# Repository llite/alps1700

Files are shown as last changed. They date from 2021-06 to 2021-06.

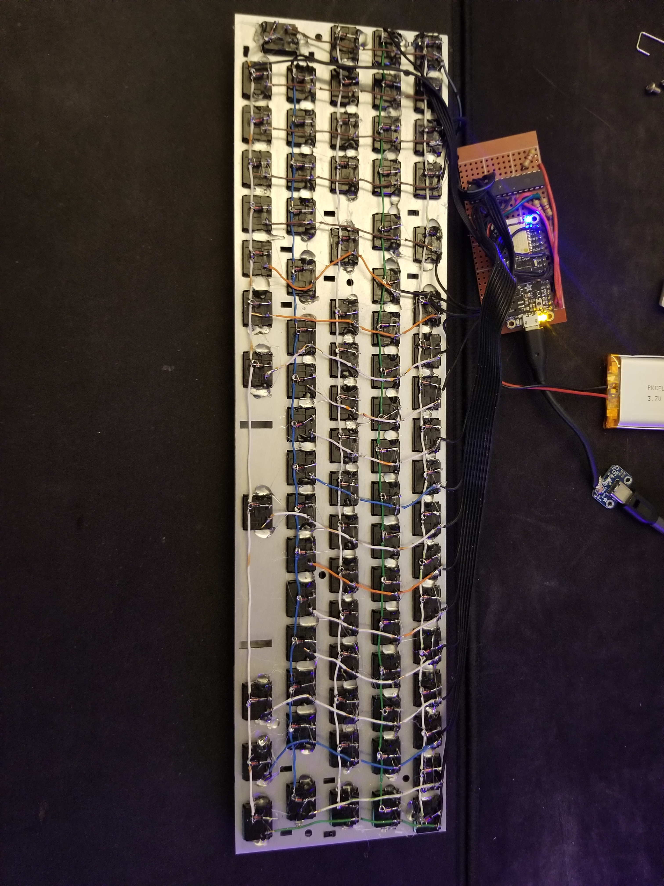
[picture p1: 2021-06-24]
images/20210624_172025.jpg

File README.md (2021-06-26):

# alps1700

A custom handwired keyboard with a similar layout to 1800 sans the function row and more compact.

Specs:
- Bluetooth LE
- USB C
- Alps SKCM Cream Damped switches
- 2000mAh battery
- [Adafruit Feather 32u4 Bluefruit LE](https://www.adafruit.com/product/2829) 

Case is 3d printed out of Formfutura's [Galaxy titanium](https://www.partsbuilt.com/galaxy-pla-titanium-silver-formfutura/). Because of printer bed size limitations it had to be printed in two parts. 

Keycaps and switches are from an [Apple Extended Keyboard II](https://deskthority.net/wiki/Apple_Extended_Keyboard_II), with 3d-printed caps for space, right-shift and num-pad 0.

Firmware is based on [Mike Roberts'](https://github.com/ecopoesis) [NEK type A](https://github.com/qmk/qmk_firmware/tree/master/keyboards/nek_type_a), with a few adjustment to account for the different layout. _Note the diodes MUST be wired in row to column layout for the firmware to work._

I see no reason this couldn't be adapted for cherry mount switches. In theory the only different would be the mounting plate.

## Parts list

| Item | Amount | link |
| --- | --- | --- |
| Alps SKCL/SKCM switches | 81 | [deskthority wiki](https://deskthority.net/wiki/Alps_SKCL/SKCM_series) |
| Keycaps | XX | Up to you |
| Switch mounting plate | 1 | [sendcutsend](https://sendcutsend.com/) |
| Feather 32u4 Bluefruit | 1 | [adafruit](https://www.adafruit.com/product/2829) |
| MCP23017 I/O Expander | 1 | [adafruit](https://www.adafruit.com/product/732) |
| Through-Hole Resistors - 4.7K | 3 | [adafruit](https://www.adafruit.com/product/2783) |
| 1N4148 Diode | 81 | [adafruit](https://www.adafruit.com/product/1641) |
| Perfboard | 1 | [adafruit](https://www.adafruit.com/product/2670) |
| Ribbon cable | 1 | [adafruit](https://www.adafruit.com/product/3890) |
| Solid core cable | 1 | [adafruit](https://www.adafruit.com/product/290) |
| Li-Po battery | 1 | [adafruit](https://www.adafruit.com/product/2011) |
| USB-C breakout | 1 | [adafruit](https://www.adafruit.com/product/4090) |
| m3 Heat-Set Inserts | 6 | [adafruit](https://www.adafruit.com/product/4256) |
| m3x5 bolts | 6 | [boltdepot](https://www.boltdepot.com/Product-Details.aspx?product=18787) |
| Filament | ~300g | [one I used](https://www.partsbuilt.com/galaxy-pla-titanium-silver-formfutura/) |

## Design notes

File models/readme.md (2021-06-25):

All the models needed to make the keyboard.

The case is to large to print in one piece on most 3d-printers so there are split models included. 

Depending on the keycap set you may need to print some keys. There are files for a 6u spacebar, 1.75u right shift, and 1u numpad 0. These are modeled off the AEK2's keycaps which have a different profile than most caps. There are libaries for printing caps like [rsheldiii's KeyV2](https://github.com/rsheldiii/keyV2) in case you need them.

Print list

| Item | Amount |
| --- | --- |
| Case-left | 1 |
| Case-right | 1 |
| Alligment-pin | 2 |
| 6u spacebar | 1 |
| 1.75u r-shift | 1 |
| 1u numpad-0  | 1 |

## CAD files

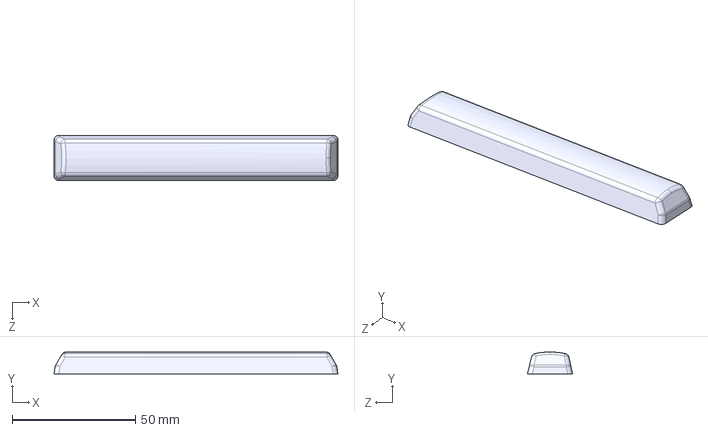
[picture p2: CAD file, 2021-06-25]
models/keycaps/space-6u.STEP
115.0 x 8.90 x 18.3 mm

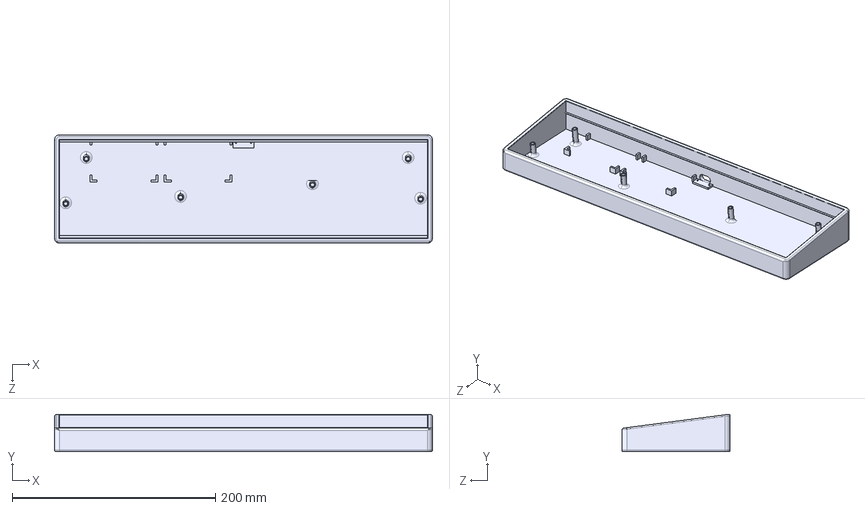
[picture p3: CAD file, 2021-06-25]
models/case.STEP
372.0 x 36.8 x 106.8 mm

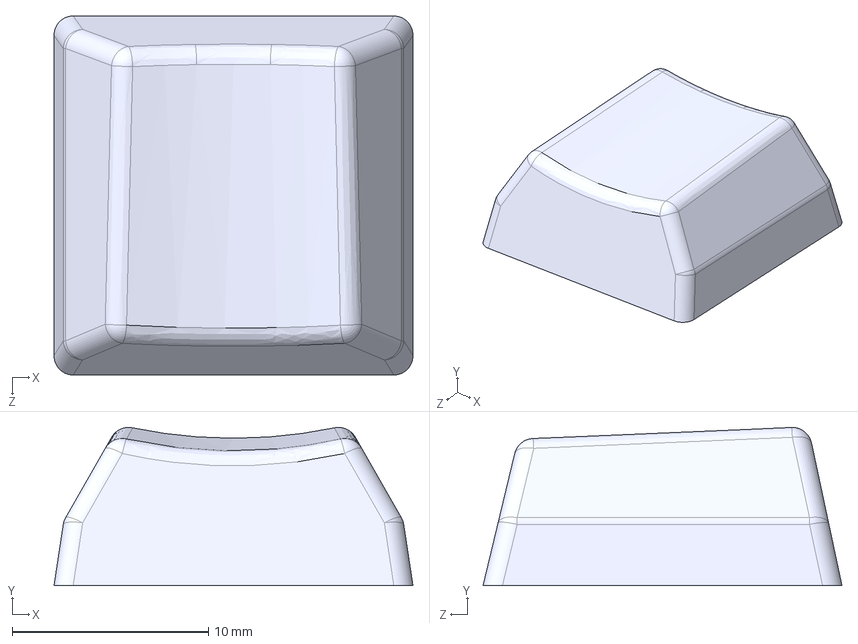
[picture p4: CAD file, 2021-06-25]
models/keycaps/RA-1U.STEP
18.3 x 8.06 x 18.3 mm

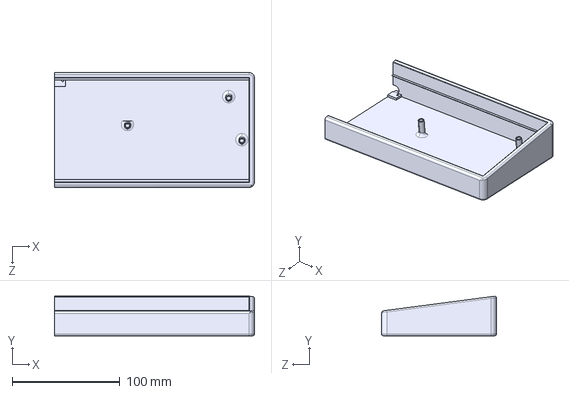
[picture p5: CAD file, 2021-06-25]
models/case-right-half.STEP
186.0 x 36.8 x 106.8 mm

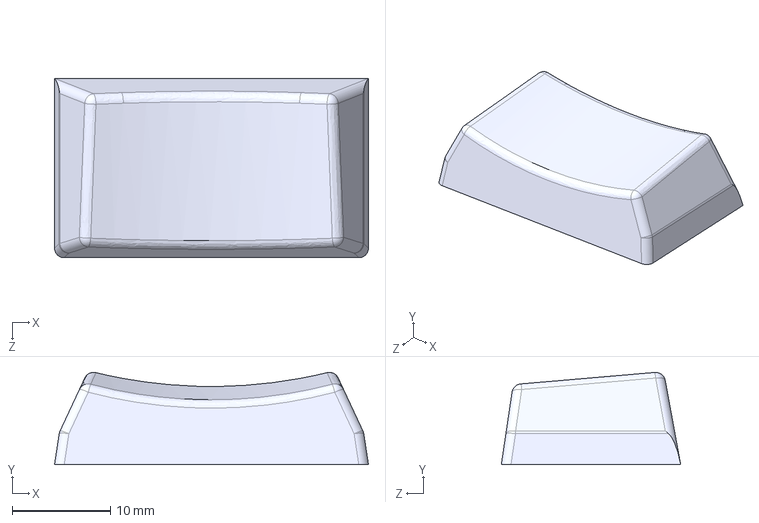
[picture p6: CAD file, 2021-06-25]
models/keycaps/RB-1.75U.STEP
32.0 x 9.41 x 18.3 mm

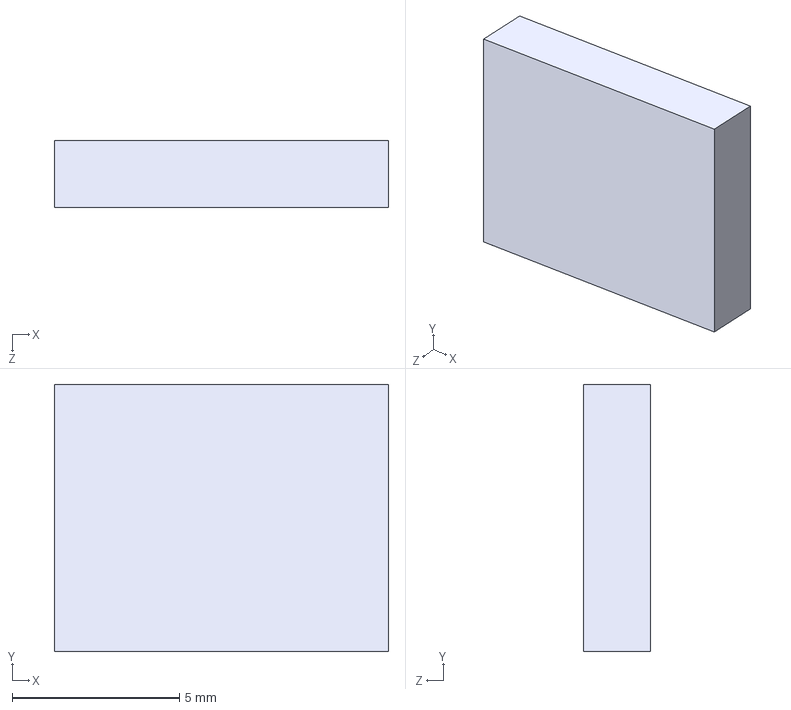
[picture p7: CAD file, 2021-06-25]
models/alignment-pin.STEP
10.0 x 8.00 x 2.00 mm

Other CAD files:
models/plate.DXF
models/case-left-half.STEP
models/alignment-pin.STL
models/case-left-half.STL
models/case-right-half.STL
models/case.STL
models/keycaps/RA-1U.STL
models/keycaps/RB-1.75U.STL
models/keycaps/space-6u.STL
